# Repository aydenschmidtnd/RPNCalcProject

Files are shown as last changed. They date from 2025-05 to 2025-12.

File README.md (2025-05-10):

# RPNCalcProject

Due to the cost of reverse polish notation (RPN) calculators, I wanted to make the attempt at creating one myself.
I would do this all from scratch making my own PCB, creating my own code, and figuring out how to create a calculator-like case.

I want to go ahead and do this with the MSP430G2533 Microcontroller since I have a development board with me with that MCU.

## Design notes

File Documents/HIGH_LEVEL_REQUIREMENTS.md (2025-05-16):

**HIGH LEVEL REQUIREMENTS**

1. Shall support addition and multiplication functionality.

2. Shall support exponent functionality.

3. Shall support trigonometric and inverse trigonometric functionality.

4. Shall support handling of degrees and radians.

5. Shall support logarithmic functionality.

6. Shall support complex math.

7. Shall RPN functionality.

8. Shall support modulus functionality.

9. Shall support switching between decimal, hex, and binary mode.

10. Shall support polar mode for complex mathematics.

11. Shall support combinations and permutation functionality.

12. Shall support factorial functionality.

13. Shall support engineering notation.

14. Shall support saving of values.

15. Shall support scientific notation.

16. Shall support absolute value functionality.

17. Shall support conversion between common units.

18. Shall support reset of all settings

19. Shall support switching the current stack and the one above it.

20. Shall support shortcuts for common constants.

21. Shall support the display of different significant digits.

22. Shall support the switching of decimals and fractions.

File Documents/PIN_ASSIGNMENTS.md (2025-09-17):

# Pin Assignments

## 16x2 LCD:

### Control
1) **Enable** = 2.0
2) **RW** = 2.1
3) **RS** = 2.2

### Shift Register
1) **SER** = 1.2 (UCA0SIMO)
2) **OE** = pulldown
3) **RCLK** = 2.4
4) **SRCLK** = 1.4 (UCA0CLK)
5) **SRCLR** = pullup

### MCP23017 IO Expander
1) **SCK** = 1.6 
2) **SDA** = 1.7
3) **A0, A1, A2** = pulldown

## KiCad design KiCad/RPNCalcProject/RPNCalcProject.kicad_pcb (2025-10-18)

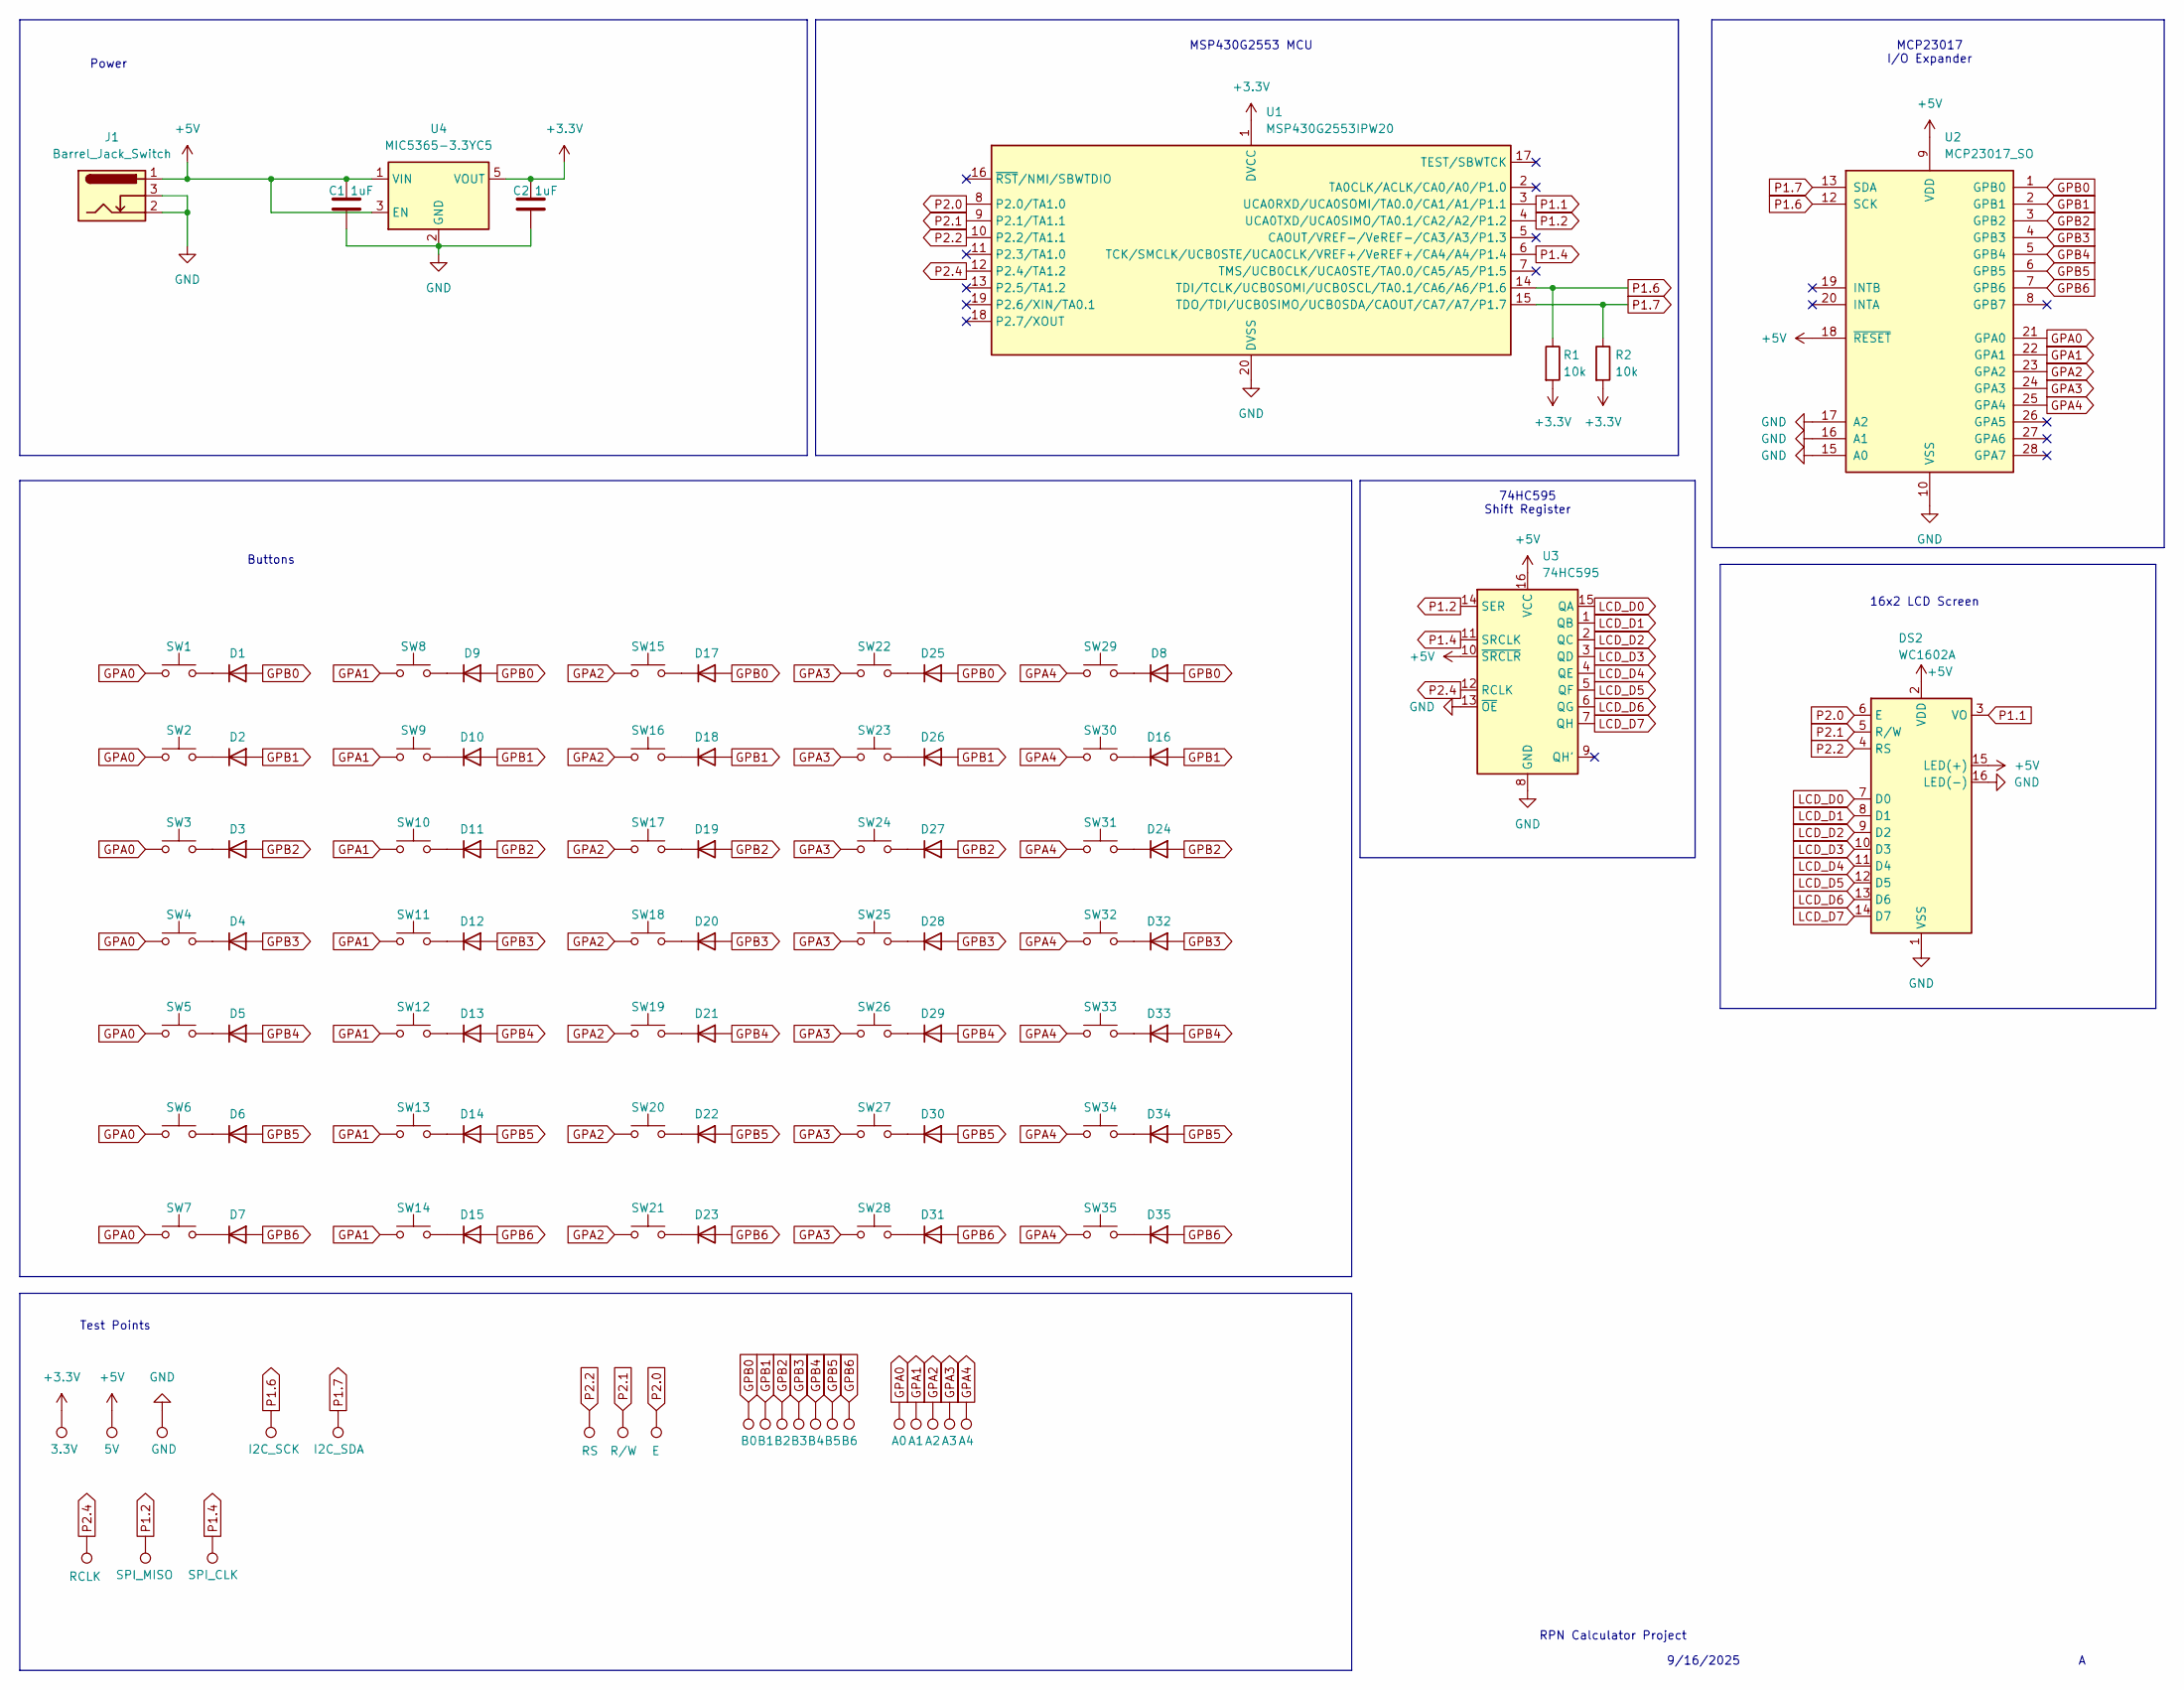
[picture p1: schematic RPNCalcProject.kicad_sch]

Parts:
C1, C2: 1uF; C_0201_0603Metric_Pad0.64x0.40mm_HandSolder
D1, D2, D3, D4, D5, D6, D7, D8, D9, D10, D11, D12, D13, D14, D15, D16, D17, D18, D19, D20, D21, D22, D23, D24, D25, D26, D27, D28, D29, D30, D31, D32, D33, D34, D35: 1N4148WS; D_DO-35_SOD27_P2.54mm_Vertical_KathodeUp
DS2: WC1602A
J1: Barrel_Jack_Switch; BarrelJack_CLIFF_FC681465S_SMT_Horizontal
R1, R2: 10k; R_0603_1608Metric_Pad0.98x0.95mm_HandSolder
SW1: RCL; Tactile momentary button
SW2: SIN; Tactile momentary button
SW3: ENTER; Tactile momentary button
SW4: SYMBOLS; Tactile momentary button
SW5: SWITCH; Tactile momentary button
SW6: CLEAR; Tactile momentary button
SW7: OFF/ON; Tactile momentary button
SW8: STACK_DOWN; Tactile momentary button
SW9: COS; Tactile momentary button
SW10: IMAGINARY; Tactile momentary button
SW11: NUM_7; Tactile momentary button
SW12: NUM_4; Tactile momentary button
SW13: NUM_1; Tactile momentary button
SW14: NUM_0; Tactile momentary button
SW15: SWAP; Tactile momentary button
SW16: TAN; Tactile momentary button
SW17: NEGATE; Tactile momentary button
SW18: NUM_8; Tactile momentary button
SW19: NUM_5; Tactile momentary button
SW20: NUM_2; Tactile momentary button
SW21: DECIMAL; Tactile momentary button
SW22: ARROW_LEFT; Tactile momentary button
SW23: POWER; Tactile momentary button
SW24: ENG_NOTATION; Tactile momentary button
SW25: NUM_9; Tactile momentary button
SW26: NUM_6; Tactile momentary button
SW27: NUM_3; Tactile momentary button
SW28: FACTORIAL; Tactile momentary button
SW29: ARROW_RIGHT; Tactile momentary button
SW30: INVERSE; Tactile momentary button
SW31: BACKSPACE; Tactile momentary button
SW32: DIVIDE; Tactile momentary button
SW33: MULTIPLY; Tactile momentary button
SW34: SUBTRACT; Tactile momentary button
SW35: ADD; Tactile momentary button
TP1: 3.3V; TestPoint_Pad_D1.0mm
TP2: 5V; TestPoint_Pad_D1.0mm
TP3: GND; TestPoint_THTPad_1.0x1.0mm_Drill0.5mm
TP4: I2C_SCK; TestPoint_Pad_D1.0mm
TP5: I2C_SDA; TestPoint_Pad_D1.0mm
TP6: SPI_MISO; TestPoint_Pad_D1.0mm
TP7: SPI_CLK; TestPoint_Pad_D1.0mm
TP16: RS; TestPoint_Pad_D1.0mm
TP17: R/W; TestPoint_Pad_D1.0mm
TP18: E; TestPoint_Pad_D1.0mm
TP19: RCLK; TestPoint_Pad_D1.0mm
TP20: B0; TestPoint_Pad_D1.0mm
TP21: B1; TestPoint_Pad_D1.0mm
TP22: B2; TestPoint_Pad_D1.0mm
TP23: B3; TestPoint_Pad_D1.0mm
TP24: B4; TestPoint_Pad_D1.0mm
TP25: B5; TestPoint_Pad_D1.0mm
TP26: B6; TestPoint_Pad_D1.0mm
TP27: A0; TestPoint_THTPad_D1.0mm_Drill0.5mm
TP28: A1; TestPoint_THTPad_D1.0mm_Drill0.5mm
TP29: A2; TestPoint_THTPad_D1.0mm_Drill0.5mm
TP30: A3; TestPoint_THTPad_D1.0mm_Drill0.5mm
TP31: A4; TestPoint_THTPad_D1.0mm_Drill0.5mm
U1: MSP430G2553IPW20; DIP-20_W7.62mm_Socket_LongPads
U2: MCP23017_SO; SOIC-28W_7.5x17.9mm_P1.27mm
U3: 74HC595; TSSOP-16_4.4x5mm_P0.65mm
U4: MIC5365-3.3YC5; SOT-353_SC-70-5

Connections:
+3.3V: C2.1, R1.2, R2.2, TP1.1, U1.1 (DVCC), U4.5 (VOUT)
+5V: C1.1, DS2.2 (VDD), DS2.15 (LED(+)), J1.1, TP2.1, U2.9 (VDD), U2.18 (~RESET), U3.10 (~SRCLR), U3.16 (VCC), U4.1 (VIN), U4.3 (EN)
GND: C1.2, C2.2, DS2.1 (VSS), DS2.16 (LED(-)), J1.2, J1.3, TP3.1, U1.20 (DVSS), U2.10 (VSS), U2.15 (A0), U2.16 (A1), U2.17 (A2), U3.8 (GND), U3.13 (~OE), U4.2 (GND)
GPA0: SW1.1 (A), SW1.2 (A), SW2.1 (A), SW2.2 (A), SW3.1 (A), SW3.2 (A), SW4.1 (A), SW4.2 (A), SW5.1 (A), SW5.2 (A), SW6.1 (A), SW6.2 (A), SW7.1 (A), SW7.2 (A), TP27.1, U2.21 (GPA0)
GPA1: SW8.1 (A), SW8.2 (A), SW9.1 (A), SW9.2 (A), SW10.1 (A), SW10.2 (A), SW11.1 (A), SW11.2 (A), SW12.1 (A), SW12.2 (A), SW13.1 (A), SW13.2 (A), SW14.1 (A), SW14.2 (A), TP28.1, U2.22 (GPA1)
GPA2: SW15.1 (A), SW15.2 (A), SW16.1 (A), SW16.2 (A), SW17.1 (A), SW17.2 (A), SW18.1 (A), SW18.2 (A), SW19.1 (A), SW19.2 (A), SW20.1 (A), SW20.2 (A), SW21.1 (A), SW21.2 (A), TP29.1, U2.23 (GPA2)
GPA3: SW22.1 (A), SW22.2 (A), SW23.1 (A), SW23.2 (A), SW24.1 (A), SW24.2 (A), SW25.1 (A), SW25.2 (A), SW26.1 (A), SW26.2 (A), SW27.1 (A), SW27.2 (A), SW28.1 (A), SW28.2 (A), TP30.1, U2.24 (GPA3)
GPA4: SW29.1 (A), SW29.2 (A), SW30.1 (A), SW30.2 (A), SW31.1 (A), SW31.2 (A), SW32.1 (A), SW32.2 (A), SW33.1 (A), SW33.2 (A), SW34.1 (A), SW34.2 (A), SW35.1 (A), SW35.2 (A), TP31.1, U2.25 (GPA4)
GPB0: D1.2 (A), D8.2 (A), D9.2 (A), D17.2 (A), D25.2 (A), TP20.1, U2.1 (GPB0)
GPB1: D2.2 (A), D10.2 (A), D16.2 (A), D18.2 (A), D26.2 (A), TP21.1, U2.2 (GPB1)
GPB2: D3.2 (A), D11.2 (A), D19.2 (A), D24.2 (A), D27.2 (A), TP22.1, U2.3 (GPB2)
GPB3: D4.2 (A), D12.2 (A), D20.2 (A), D28.2 (A), D32.2 (A), TP23.1, U2.4 (GPB3)
GPB4: D5.2 (A), D13.2 (A), D21.2 (A), D29.2 (A), D33.2 (A), TP24.1, U2.5 (GPB4)
GPB5: D6.2 (A), D14.2 (A), D22.2 (A), D30.2 (A), D34.2 (A), TP25.1, U2.6 (GPB5)
GPB6: D7.2 (A), D15.2 (A), D23.2 (A), D31.2 (A), D35.2 (A), TP26.1, U2.7 (GPB6)
LCD_D0: DS2.7 (D0), U3.15 (QA)
LCD_D1: DS2.8 (D1), U3.1 (QB)
LCD_D2: DS2.9 (D2), U3.2 (QC)
LCD_D3: DS2.10 (D3), U3.3 (QD)
LCD_D4: DS2.11 (D4), U3.4 (QE)
LCD_D5: DS2.12 (D5), U3.5 (QF)
LCD_D6: DS2.13 (D6), U3.6 (QG)
LCD_D7: DS2.14 (D7), U3.7 (QH)
unnamed: D1.1 (K), SW1.3 (B), SW1.4 (B)
unnamed: D2.1 (K), SW2.3 (B), SW2.4 (B)
unnamed: D3.1 (K), SW3.3 (B), SW3.4 (B)
unnamed: D4.1 (K), SW4.3 (B), SW4.4 (B)
unnamed: D5.1 (K), SW5.3 (B), SW5.4 (B)
unnamed: D6.1 (K), SW6.3 (B), SW6.4 (B)
unnamed: D7.1 (K), SW7.3 (B), SW7.4 (B)
unnamed: D8.1 (K), SW29.3 (B), SW29.4 (B)
unnamed: D9.1 (K), SW8.3 (B), SW8.4 (B)
unnamed: D10.1 (K), SW9.3 (B), SW9.4 (B)
unnamed: D11.1 (K), SW10.3 (B), SW10.4 (B)
unnamed: D12.1 (K), SW11.3 (B), SW11.4 (B)
unnamed: D13.1 (K), SW12.3 (B), SW12.4 (B)
unnamed: D14.1 (K), SW13.3 (B), SW13.4 (B)
unnamed: D15.1 (K), SW14.3 (B), SW14.4 (B)
unnamed: D16.1 (K), SW30.3 (B), SW30.4 (B)
unnamed: D17.1 (K), SW15.3 (B), SW15.4 (B)
unnamed: D18.1 (K), SW16.3 (B), SW16.4 (B)
unnamed: D19.1 (K), SW17.3 (B), SW17.4 (B)
unnamed: D20.1 (K), SW18.3 (B), SW18.4 (B)
unnamed: D21.1 (K), SW19.3 (B), SW19.4 (B)
unnamed: D22.1 (K), SW20.3 (B), SW20.4 (B)
unnamed: D23.1 (K), SW21.3 (B), SW21.4 (B)
unnamed: D24.1 (K), SW31.3 (B), SW31.4 (B)
unnamed: D25.1 (K), SW22.3 (B), SW22.4 (B)
unnamed: D26.1 (K), SW23.3 (B), SW23.4 (B)
unnamed: D27.1 (K), SW24.3 (B), SW24.4 (B)
unnamed: D28.1 (K), SW25.3 (B), SW25.4 (B)
unnamed: D29.1 (K), SW26.3 (B), SW26.4 (B)
unnamed: D30.1 (K), SW27.3 (B), SW27.4 (B)
unnamed: D31.1 (K), SW28.3 (B), SW28.4 (B)
unnamed: D32.1 (K), SW32.3 (B), SW32.4 (B)
unnamed: D33.1 (K), SW33.3 (B), SW33.4 (B)
unnamed: D34.1 (K), SW34.3 (B), SW34.4 (B)
unnamed: D35.1 (K), SW35.3 (B), SW35.4 (B)
P1.1: DS2.3 (VO), U1.3 (UCA0RXD/UCA0SOMI/TA0.0/CA1/A1/P1.1)
P1.2: TP6.1, U1.4 (UCA0TXD/UCA0SIMO/TA0.1/CA2/A2/P1.2), U3.14 (SER)
P1.4: TP7.1, U1.6 (TCK/SMCLK/UCB0STE/UCA0CLK/VREF+/VeREF+/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), U3.11 (SRCLK)
P1.6: R1.1, TP4.1, U1.14 (TDI/TCLK/UCB0SOMI/UCB0SCL/TA0.1/CA6/A6/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), U2.12 (SCK)
P1.7: R2.1, TP5.1, U1.15 (TDO/TDI/UCB0SIMO/UCB0SDA/CAOUT/CA7/A7/P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), U2.13 (SDA)
P2.0: DS2.6 (E), TP18.1, U1.8 (P2.0/TA1.0)
P2.1: DS2.5 (R/W), TP17.1, U1.9 (P2.1/TA1.1)
P2.2: DS2.4 (RS), TP16.1, U1.10 (P2.2/TA1.1)
P2.4: TP19.1, U1.12 (P2.4/TA1.2), U3.12 (RCLK)

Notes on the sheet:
74HC595 Shift Register
Buttons
MSP430G2553 MCU
9/16/2025
MCP23017 I/O Expander
16x2 LCD Screen
RPN Calculator Project
Test Points
Power

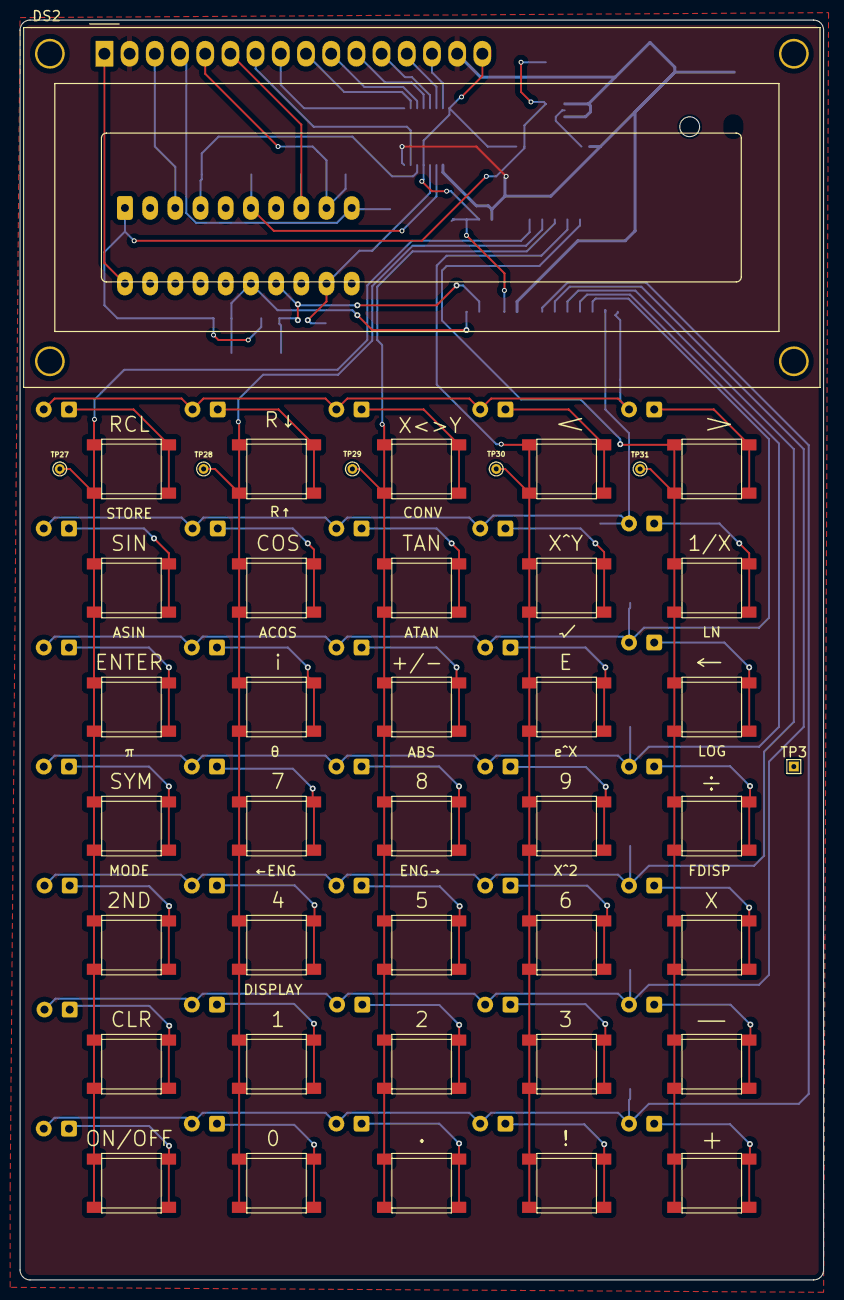
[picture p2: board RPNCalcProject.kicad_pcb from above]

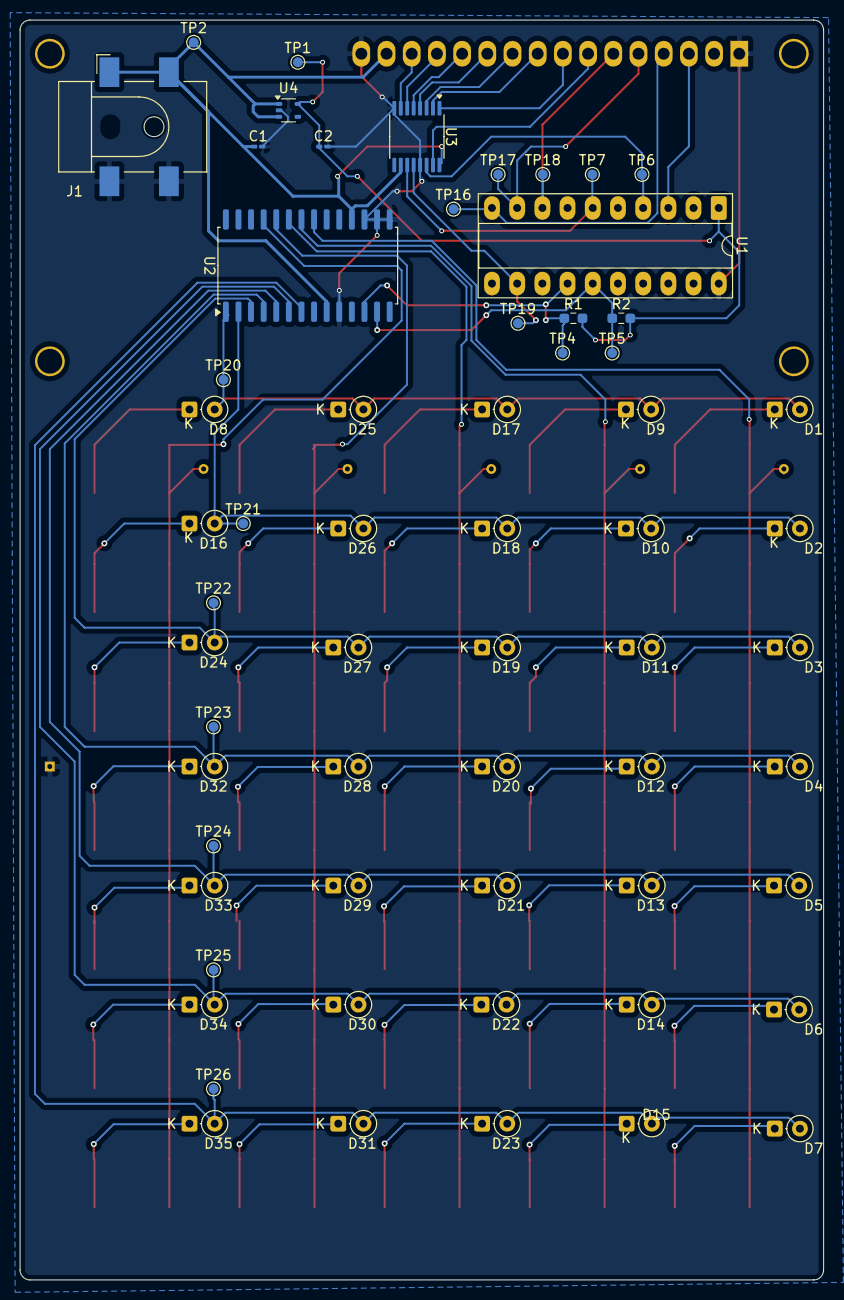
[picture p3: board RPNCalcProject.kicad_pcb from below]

Board: 2 copper layers, 81.0 x 127.0 mm, 103 parts (61 on the bottom side), 67 nets.

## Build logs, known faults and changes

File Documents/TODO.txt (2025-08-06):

1) Figure out how many buttons I want

2) Figure out how I want buttons to be handled

3) Attach buttons to breadboard and MCU

4) Create button logic

5) Test button logic

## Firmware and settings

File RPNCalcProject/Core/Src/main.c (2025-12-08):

#include <msp430.h>
#include <stdint.h>
#include <stdlib.h>
#include <stdbool.h>
#include <stdio.h>

#include "ShiftRegisterDriver.h"
#include "IoExpanderDriver.h"
#include "LcdDriver.h"
#include "Timer.h"
#include "Main.h"

static void InitClockTo16MHz(void);

void main(void)
{
    WDTCTL = WDTPW + WDTHOLD; //Stop Watchdog Timer
    
    InitClockTo16MHz();
    /*Init Peripherals*/
    InitLcdPeripherals();
    Init74HC595Peripherals();
    InitMCP23017Peripherals();
    /*Init Devices*/
    InitMCP23017();
    InitLCD();

    InitTimer();

    bool writeInstruction = true;
    uint8_t buttonCheck = 100;

    uint64_t currentTime = 0;
    uint64_t pastTime = 0;

    bool flagOne = false;
    bool flagTwo = false;
    bool flagThree = false;
    bool flagFour = false;
    char LCD_Buffer[MAX_LCD_BUFFER] = "                ";
    uint8_t index = 0;
    while(true)
    {
        WriteMCP23017(0x12, ~0x01);  //Turn COL 1 on
        __delay_cycles(100000);
        buttonCheck = ReadMCP23017(0x13);
        switch(buttonCheck)
        {
            case 1:
                if(flagOne == false)
                {
                    LCD_Buffer[index++] = '1';
                    flagOne = true;
                }
                break;
            case 2: 
                if(flagTwo == false)
                {
                    LCD_Buffer[index++] = '3';
                    flagTwo = true;
                }
                break;
            default:
                break;
        }
        __delay_cycles(100000);
        if(ReadMCP23017(0x13) == 0)
        {
            flagOne = false;
            flagTwo = false;
        } 
        if(index == 16){index = 0;}
        WriteMCP23017(0x12, 0x01);
        __delay_cycles(100000);

        WriteMCP23017(0x12, ~0x02);
        __delay_cycles(100000);
        buttonCheck = ReadMCP23017(0x13);
        switch(buttonCheck)
        {
            case 1:
                if(flagThree == false)
                {
                    LCD_Buffer[index++] = '2';
                    flagThree = true;
                }
                break;
            case 2: 
                if(flagFour == false)
                {
                    LCD_Buffer[index++] = '4';
                    flagFour = true;
                }
                break;
            default:
                break;
        }
        __delay_cycles(100000);
        if(ReadMCP23017(0x13) == 0)
        {
            flagThree = false;
            flagFour = false;
        }
        if(index == 16){index = 0;}
        
        WriteMCP23017(0x12, 0x02);
        __delay_cycles(100000);

        WriteLCDString(LCD_LINE_ONE, 0, LCD_Buffer);
    }
}

static void InitClockTo16MHz()
{
    if (CALBC1_16MHZ==0xFF)                  // If calibration constant erased
    {
        while(1);                            // do not load, trap CPU!!
    }
    DCOCTL = 0;                              // Select lowest DCOx and MODx settings
    BCSCTL1 = CALBC1_16MHZ;                  // Set DCO
    DCOCTL = CALDCO_16MHZ;                   
}

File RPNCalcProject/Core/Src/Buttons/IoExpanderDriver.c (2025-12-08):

#include <msp430.h>
#include <stdint.h>
#include <stdbool.h>
#include "IoExpanderDriver.h"

/*PORT 2*/
#define I2CSCL BIT6
#define I2CSDA BIT7

#define MCP23017_DEVICE_ADDRESS (0x20U)

typedef enum
{
    MCP23017_IODIRA_COMMAND_OUTPUT      = 0x00,
    MCP23017_IODIRB_COMMAND_INPUT       = 0x7F,
    MCP23017_GPPUB_COMMAND_PULL_UP      = 0x7F,
    MCP23017_IPOLB_COMMAND_INVERT_INPUT = 0x7F,
} MCP23017_COMMANDS;

typedef enum
{
    MCP23017_ADDRESS_IODIRA = 0x00,
    MCP23017_ADDRESS_IODIRB = 0x01,
    MCP23017_ADDRESS_IPOLB  = 0x03,
    MCP23017_ADDRESS_GPPUB  = 0x0D,
} MCP23017_ADDRESS;

static bool WriteMCP23017(uint8_t registerAddress, uint8_t data);
static uint8_t ReadMCP23017(uint8_t registerAddress);

void InitMCP23017Peripherals(void)
{
    P1SEL  |= I2CSCL + I2CSDA;                    // Assign pins 1.6 and 1.7 to I2C
    P1SEL2 |= I2CSCL + I2CSDA;                    // Assign pins 1.6 and 1.7 to I2C

    UCB0CTL1 |= UCSWRST;                          // Enable SW reset
    UCB0CTL0 = UCMST + UCMODE_3 + UCSYNC;         // I2C Master, synchronous mode, 7-bit addressing
    UCB0CTL1 = UCSSEL_2 + UCSWRST;                // Use SMCLK, keep SW reset

    UCB0BR0 = 160;                                // fSCL = SMCLK/160 = ~100kHz
    UCB0BR1 = 0;                                  // fSCL = SMCLK/160 = ~100kHz

    UCB0I2CSA = MCP23017_DEVICE_ADDRESS;          // Slave address is 0x20 for MCP23017

    UCB0CTL1 &= ~UCSWRST;                         // Clear SW reset, resume operation
}

void InitMCP23017(void)
{
    WriteMCP23017(MCP23017_ADDRESS_IODIRA, MCP23017_IODIRA_COMMAND_OUTPUT);      // Set PORTA to outputs
    WriteMCP23017(MCP23017_ADDRESS_IODIRB, MCP23017_IODIRB_COMMAND_INPUT);       // Set PORTB to inputs
    WriteMCP23017(MCP23017_ADDRESS_GPPUB,  MCP23017_GPPUB_COMMAND_PULL_UP);      // Set PORTB pull-ups (100k)
    WriteMCP23017(MCP23017_ADDRESS_IPOLB,  MCP23017_IPOLB_COMMAND_INVERT_INPUT); // Invert PORTB input readings
}

static bool WriteMCP23017(uint8_t registerAddress, uint8_t data)
{
    UCB0CTL1 |= UCTR + UCTXSTT;                   // I2C start condition TXs
    UCB0TXBUF = registerAddress;                  // Set which register to write to
    while(UCB0CTL1 & UCTXSTT);                    // Loop until I2C STT is sent
    while((IFG2 & UCB0TXIFG) == 0);               // Wait til data is fully sent

    UCB0TXBUF = data;
    while((IFG2 & UCB0TXIFG) == 0);               // Wait til data is fully sent

    UCB0CTL1 |= UCTXSTP;                          // Stop bit
    while (UCB0CTL1 & UCTXSTP);                   // Wait til stop bit is sent

    return true;                                  
}

static uint8_t ReadMCP23017(uint8_t registerAddress)
{
    UCB0CTL1 |= UCTR + UCTXSTT;                   // I2C start condition TXs
    UCB0TXBUF = registerAddress;                  // Set which register to write to
    while(UCB0CTL1 & UCTXSTT);                    // Loop until I2C STT is sent
    while((IFG2 & UCB0TXIFG) == 0);               // Wait til data is fully sent

    UCB0CTL1 &= ~UCTR;                            // Set I2C for read operation
    UCB0CTL1 |= UCTXSTT;                          // I2C start condition
    while(UCB0CTL1 & UCTXSTT);                    // Loop until I2C STT is sent
        
    UCB0CTL1 |= UCTXSTP;                          // Stop bit
    while(UCB0CTL1 & UCTXSTP);                    // Wait til stop bit is sent

    while((IFG2 & UCB0RXIFG) == 0);               // Wait til RX buffer is full
    return UCB0RXBUF;
}

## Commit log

2025-07-27 Initial commit of documentation.
    This includes
    1) Draft of high level requirements
    2) Pin assignments
2025-07-27 Initial commit of MAIN and SPI code.
2025-08-06 Commit of Kicad Files
    [RPNCalcProject.kicad_pcb, RPNCalcProject.kicad_sch]
2025-08-06 Commit of I2C module
2025-08-06 Initial commit of timer module set for 1 ms
2025-08-06 Small changes to SPI
    Added delay at end; Made SPI 500kHz with respect to 16 Mhz SMCLK
2025-08-07 Update to pin assignments
2025-08-08 Updated kicad schematic
    [RPNCalcProject.kicad_sch]
2025-09-16 Updated schematic, added button layout plan
    [Button Layout.xlsx, RPNCalcProject.kicad_sch]
2025-09-17 Updated Kicad PCB/Schematic
    Finished schematic and almost finished routing PCB
    [RPNCalcProject.kicad_pcb]
2025-09-17 Updated pin assignment / Removed calculator buttons md
2025-11-11 Add KiCad project backups and .vscode to .gitignore
2025-11-11 Add GerberFiles directory to .gitignore
